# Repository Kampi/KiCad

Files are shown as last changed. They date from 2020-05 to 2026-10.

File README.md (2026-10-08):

# KiCad

## Table of Contents

- [KiCad](#kicad)
  - [Table of Contents](#table-of-contents)
  - [About](#about)
  - [Setup](#setup)
    - [Required Tools](#required-tools)
    - [Setup Instructions](#setup-instructions)
      - [1. Install the Tools](#1-install-the-tools)
      - [2. Clone the Repository](#2-clone-the-repository)
      - [3. Set the KICAD\_LIBRARY Environment Variable](#3-set-the-kicad_library-environment-variable)
      - [4. Authenticate Git and the GitHub CLI](#4-authenticate-git-and-the-github-cli)
      - [5. Configure VS Code and GitHub Copilot](#5-configure-vs-code-and-github-copilot)
    - [Project Initialization Script](#project-initialization-script)
      - [What the Script Does](#what-the-script-does)
      - [Usage](#usage)
      - [Non-Interactive Usage](#non-interactive-usage)
  - [Directories](#directories)
  - [PCB Template Structure](#pcb-template-structure)
    - [Template Naming Convention](#template-naming-convention)
    - [Available Templates](#available-templates)
    - [Template Selection](#template-selection)
    - [Adding Custom Templates](#adding-custom-templates)
  - [CI/CD Pipelines](#cicd-pipelines)
    - [PCB](#pcb)
    - [Changelog Check](#changelog-check)
    - [Documentation](#documentation)
    - [Code Style Check](#code-style-check)
    - [PlatformIO Firmware](#platformio-firmware)
    - [ESP-IDF Component](#esp-idf-component)
    - [Component Release](#component-release)
  - [Release Workflow](#release-workflow)
    - [Version Scheme](#version-scheme)
    - [create-dev-branch Skill](#create-dev-branch-skill)
    - [create-release Skill](#create-release-skill)
      - [Prerequisites](#prerequisites)
      - [Usage of the Skill](#usage-of-the-skill)
      - [What the Skill Does](#what-the-skill-does)
      - [Files Changed by the Skill](#files-changed-by-the-skill)
  - [GitHub Secrets Configuration](#github-secrets-configuration)
  - [GitLab CI/CD Variables](#gitlab-cicd-variables)
  - [How to Obtain API Keys](#how-to-obtain-api-keys)
  - [Resources](#resources)
  - [Maintainer](#maintainer)

## About

My private KiCad repository with symbols, 3D models (most of the models are delivered by the part manufacturer, [GrabCAD](https://grabcad.com/), [3D ContentCentral](https://www.3dcontentcentral.com/Default.aspx) or [SnapEDA](https://www.snapeda.com/)), and footprints for different projects.

Please write an e-mail to [DanielKampert@kampis-elektroecke.de](mailto:DanielKampert@kampis-elektroecke.de) if you have any questions.

## Setup

### Required Tools

| Tool | Version | Needed for |
| ---- | --- | --- |
| [KiCad](https://www.kicad.org/download/) | 10.0 or later | Schematic and PCB design, `kicad-cli` for ERC/DRC. The template files and the PCB pipeline use KiCad 10 |
| [Git](https://git-scm.com/downloads) | Current version | Repository handling, init scripts, releases |
| [Python 3](https://www.python.org/downloads/) | 3.8 or later | JSON processing in `init-project.sh`, file updates in the `create-dev-branch` and `create-release` skills |
| Bash | 4.0 or later | `init-project.sh`, project scripts and the `create-dev-branch` and `create-release` skills (Git Bash or WSL on Windows) |
| PowerShell | 5.1 or later | `init-project.ps1` (Windows only) |
| curl | Current version | License download in `init-project.sh` |
| [GitHub CLI](https://cli.github.com/) (`gh`) | Current version | Pushing with the logged in GitHub user in the `create-dev-branch` and `create-release` skills, watching pipelines and reading releases in the `create-release` skill |
| [Visual Studio Code](https://code.visualstudio.com/) | Current version | Running the `create-dev-branch` and `create-release` skills |
| [GitHub Copilot](https://github.com/features/copilot) | Copilot subscription | Agent mode for the `create-dev-branch` and `create-release` skills |
| [KiBot](https://github.com/INTI-CMNB/KiBot) | Optional | Local output generation with `kibot_launch.sh` (the CI/CD pipeline uses its own container) |

### Setup Instructions

#### 1. Install the Tools

**Linux (Debian/Ubuntu):**

```bash
sudo apt update
sudo apt install git python3 curl
```

Install KiCad from the [KiCad download page](https://www.kicad.org/download/linux/) and the GitHub CLI by following the [official installation instructions](https://github.com/cli/cli/blob/trunk/docs/install_linux.md). The distribution packages of both tools are often outdated.

**Windows (PowerShell):**

```powershell
winget install --id KiCad.KiCad
winget install --id Git.Git
winget install --id Python.Python.3.12
winget install --id GitHub.cli
winget install --id Microsoft.VisualStudioCode
```

Add the `bin` directory of KiCad (e.g. `C:\Program Files\KiCad\10.0\bin`) to the `PATH`, so that `kicad-cli` can be found.

Verify the installation:

```bash
git --version
python3 --version
kicad-cli version
gh --version
```

#### 2. Clone the Repository

The template and the plugins are included as Git submodules, so clone the repository recursively:

```bash
git clone --recurse-submodules https://github.com/Kampi/KiCad
```

For an existing clone, fetch the submodules with `git submodule update --init --recursive`.

#### 3. Set the KICAD_LIBRARY Environment Variable

Create an environment variable with the name `KICAD_LIBRARY` and set it to the location of the repository.

**Linux/macOS:**

```bash
echo 'export KICAD_LIBRARY="$HOME/Projects/KiCad"' >> ~/.bashrc
source ~/.bashrc
```

**Windows (PowerShell):**

```powershell
[Environment]::SetEnvironmentVariable("KICAD_LIBRARY", "C:\KiCad", "User")
```

Restart KiCad and all terminals afterwards.

#### 4. Authenticate Git and the GitHub CLI

```bash
git config --global user.name "John Doe"
git config --global user.email "john.doe@example.com"
gh auth login --hostname github.com --git-protocol https --web
gh auth setup-git
gh auth status
```

`gh auth setup-git` makes Git use the credentials of the active GitHub CLI account, so `git push` and `gh` always use the same account. With several accounts, add them with `gh auth login` and switch with `gh auth switch --user <username>`.

#### 5. Configure VS Code and GitHub Copilot

1. Install the GitHub Copilot extension and sign in with your GitHub account
2. Open the generated project folder (not the `KiCad` repository) in VS Code, so that the skills in `.github/skills/` are found
3. Make sure agent skills are enabled (`chat.useAgentSkills`, enabled by default)
4. **Windows only**: The skill uses Bash commands. Set Git Bash as the terminal profile for agent commands:

   ```json
   "chat.tools.terminal.terminalProfile.windows": {
       "path": "C:\\Program Files\\Git\\bin\\bash.exe"
   }
   ```

### Project Initialization Script

The `Scripts` directory contains initialization scripts for creating new projects from the template:

- `Scripts/init-project.ps1` - Windows PowerShell script
- `Scripts/init-project.sh` - Linux/macOS Bash script

The scripts find the template via the `KICAD_LIBRARY` environment variable or, if it is not set, relative to their own location.

#### Project Types

The scripts ask for the project type and keep only the directories, the firmware profile and the GitHub Actions workflows that belong to it:

| No. | Project type | Hardware | Firmware profile | Result |
| --- | --- | --- | --- | --- |
| 1 | Hardware (default) | Yes | `firmware/blank` | KiCad project with an empty firmware directory |
| 2 | Hardware with PlatformIO firmware | Yes | `firmware/platformio` | KiCad project and a PlatformIO project in `firmware/` |
| 3 | PlatformIO firmware | No | `firmware/platformio` | PlatformIO project in `firmware/` |
| 4 | ESP-IDF component | No | `firmware/esp-idf-component` | Component in the repository root |

- **PlatformIO profile**: ESP32 (`esp32dev`) with the ESP-IDF framework. The platform `espressif32 @ 7.1.3` contains ESP-IDF v6.1. Hardware independent code in `lib/` is tested on the host with the `native` environment
- **ESP-IDF component profile**: Component for ESP-IDF v6.1 or later with `idf_component.yml`, an example project in `examples/basic` and its own `README.md` and `CHANGELOG.md`. The sources are named after the repository (`my-component` becomes `my_component.h`)
- Project types without hardware get no KiCad project, no `hw-*` workflows and no release skills. The GitLab CI pipelines are not adapted to the project type yet
- A component cannot be combined with hardware in one repository, because the component release and the hardware release both use the tag `x.y.z`

#### What the Script Does

1. **Project metadata**: Prompts for project name, board name, designer, email, repository URL, company, main branch, target directory and the [project type](#project-types)
2. **PCB template selection** (project types with hardware): Lists the PCB templates from `Template-Project/hardware/` and applies the selected one
3. **Project structure**: Copies the complete template (hardware, firmware, CAD, 3D print, scripts, GitHub Actions workflows, GitLab CI pipelines and agent skills), removes template artifacts such as backups, `VARIABLES.md` and the Git data of the template, and applies the project type
4. **Renaming**: Renames the `hardware` directory to the lowercase board name and all `Template.*` files to `<BoardName>.*`
5. **Metadata**: Updates the text variables in the `.kicad_pro` file (`PROJECT_NAME`, `BOARD_NAME`, `DESIGNER`, `COMPANY`, release date and revision), the sheet title of the main schematic, `kibot_main.yaml` and the workflow settings
6. **License**: Prompts for an open source license (or no license) and downloads the license text
7. **Placeholders**: Replaces all `${...}` placeholders in every text file of the project, including the GitLab CI pipelines and the agent skills
8. **Documentation**: Creates the AsciiDoc scaffolding in `firmware/docs/` (not for the ESP-IDF component)
9. **Git repository**: Initializes the repository with the main branch, the remote `origin`, the commit message template `.github/.commit-msg-template` and an initial commit, and optionally pushes it

#### Usage

**Windows (PowerShell):**

```powershell
cd C:\path\to\KiCad
.\Scripts\init-project.ps1
```

**Linux/macOS (Bash):**

```bash
cd /path/to/KiCad
./Scripts/init-project.sh
```

The script guides you through an interactive setup. Afterwards the target directory contains a fully configured KiCad project. The Bash script checks whether Python 3 is installed and prints installation instructions if it is missing.

#### Non-Interactive Usage

For automated or scripted usage, you can pipe all inputs to the initialization script using `echo`:

**Windows (PowerShell):**

```powershell
"MyProject`nMyBoard`nJohn Doe`njohn.doe@example.com`nhttps://github.com/user/repo`nMyCompany`nmain`nC:\Projects`n1`n1`n1`nn" | .\Scripts\init-project.ps1
```

**Linux/macOS (Bash):**

```bash
echo -e "MyProject\nMyBoard\nJohn Doe\njohn.doe@example.com\nhttps://github.com/user/repo\nMyCompany\nmain\n/home/$(whoami)/projects\n1\n1\n1\nn" | ./Scripts/init-project.sh
```

**Input Order:**

1. Project name (e.g., "MyProject")
2. KiCad board name (e.g., "MyBoard", or press Enter to use project name)
3. Designer name (e.g., "John Doe")
4. Designer email (e.g., `john.doe@example.com`)
5. GitHub repository URL (e.g., `https://github.com/user/repo`) - username and repository name are extracted automatically
6. Company name (optional, or press Enter to skip)
7. Main branch name (default: "main")
8. Target directory (default: current directory)
9. Project type selection (1-4, default: "1" for hardware, see [Project Types](#project-types))
10. PCB template selection (number, e.g., "1" for first template). Only asked for project types with hardware, leave it out for the types 3 and 4
11. License selection (1-11, e.g., "1" for MIT)
12. Push to GitHub now (y/N, default: no)

**Note:** Empty values (just `\n` or backtick-n in PowerShell) will use the default value for that field.

## Directories

The repository contains the following directories and files:

- `3D`: 3D models in STEP format used by the library
- `Applications`: Additional applications, e.g. the Part-DB integration
- `Design-Blocks`: KiCad design blocks
- `Drawings`: Inventor projects for different 3D models
- `Footprints`: Part footprints
- `GitHub`: Third-party libraries as Git submodules (Espressif KiCad libraries)
- `Layout`: Drawing sheet templates
- `Plugins`: KiCad plugins as Git submodules (KiCad Project Initialization Plugin)
- `Scripts`: Project initialization scripts
- `Symbols`: Part symbols
- `Template-Project`: Project template (Git submodule)
- `KiCad Workflow.md`: Development workflow, version numbering and GitHub workflow
- `AGENTS.md`: Project guidelines for AI coding agents (GitHub Copilot, Claude Code, Codex, Cursor and others). `.github/copilot-instructions.md` and `CLAUDE.md` only point to it. Rules for single areas are in `.github/instructions/`

## PCB Template Structure

The project template supports multiple PCB stackup configurations through template files. Templates must be placed in the `Template-Project/hardware/` directory.

### Template Naming Convention

PCB template files must follow this exact naming pattern:

```sh
Template - <manufacturer>_<thickness>_<layers>-layer.kicad_pcb
```

**Components:**

- `Template - ` - Fixed prefix (required)
- `<manufacturer>` - PCB manufacturer name (e.g., pcbway, jlcpcb, oshpark)
- `<thickness>` - Board thickness with unit (e.g., 1.6mm, 0.8mm, 2.0mm)
- `<layers>` - Number of copper layers (e.g., 2, 4, 6)
- `-layer.kicad_pcb` - Fixed suffix (required)

### Available Templates

- `Template - pcbway_1.6mm_2-layer.kicad_pcb` - PCBWay, 1.6mm thickness, 2 layers
- `Template - pcbway_1.6mm_4-layer.kicad_pcb` - PCBWay, 1.6mm thickness, 4 layers

### Template Selection

During project initialization, the script will:

1. Scan the `Template-Project/hardware/` directory for all template files
2. Parse the manufacturer, thickness, and layer count from each filename
3. Present an interactive menu with available templates
4. Copy the selected template as the base PCB file for the new project and remove the unused templates

### Adding Custom Templates

To add a new PCB template:

1. Create a KiCad PCB file with your desired stackup and design rules
2. Name the file following the convention above
3. Place it in the `Template-Project/hardware/` directory
4. The template will automatically appear in the selection menu

**Template Requirements:**

- Must be a valid `.kicad_pcb` file
- Should include appropriate design rules for the manufacturer
- Should contain stackup configuration matching the specified layer count
- Recommended to include manufacturer-specific constraints (trace width, spacing, etc.)

## CI/CD Pipelines

The project template contains pipelines for GitHub Actions (`Template-Project/.github/workflows/`) and GitLab CI (`Template-Project/.gitlab/ci/`, included by `Template-Project/.gitlab-ci.yml`).

The GitHub Actions workflows are grouped by a prefix in the file name and in the workflow name, so they are listed together in the Actions view. The initialization script removes the workflows that do not belong to the project type.

| Prefix | Workflow name | Area | Runs for |
| --- | --- | ---- | --- |
| `hw-` | `Hardware / ...` | KiCad project | Changes in the hardware directory |
| `fw-` | `Firmware / ...` | Firmware and components | Changes in the firmware sources |
| `docs-` | `Documentation / ...` | Documentation | Changes in `firmware/docs/` |
| `common-` | `Common / ...` | All project types | Every push and pull request |

| Pipeline | GitHub Actions | GitLab CI |
| --- | --- | --- |
| PCB | `hw-pcb.yaml` | `pcb.gitlab-ci.yml` |
| Changelog check | `common-changelog.yaml` | `changelog.gitlab-ci.yml` |
| Documentation | `docs-build.yaml` | `documentation.gitlab-ci.yml` |
| Code style check (AStyle) | `fw-format.yaml` | `astyle.gitlab-ci.yml` |
| Code style check (West) | - | `west-astyle.gitlab-ci.yml` |
| PlatformIO firmware | `fw-platformio.yaml` | - |
| ESP-IDF component | `fw-esp-component.yaml` | - |
| Component release (ESP-IDF) | `fw-esp-component-release.yaml` | `esp-component-release.gitlab-ci.yml` |

### PCB

**Trigger**: Push to `dev` or a development branch `x.y.z_Dev` / `x.y_Dev`, push of a version tag `x.y.z`, or manual start. The GitHub workflow only runs for branch pushes that change the hardware directory or `hw-pcb.yaml`. Tag pushes always start it

A push to `main` or `master` does not start the GitHub workflow. The main branch only receives releases, and a release is built by its tag. The GitLab pipeline still runs for `main` and `master` (except changes to `*.md`)

A branch `x.y_Dev` only triggers the build. Releases always use the three-part [version scheme](#version-scheme) `x.y.z`

Generates the hardware outputs with KiBot in the `kicad10_auto_full` container:

- **Variant-based builds**: Uses the variant from `kibot_variant`. Tag pushes always use `RELEASED`
- **Outputs**: Schematic PDF, Gerbers, drill files, BoM, assembly documents, 3D renders and reports. The outputs are uploaded as workflow artifact (GitLab: job artifact) and not committed. Only the netlist XML is pushed back to the branch, because the next run reads the sheet titles from it
- **ERC/DRC checks**: Only for the `CHECKED` and `RELEASED` variants
- **BoM check**: `scripts/python/check-bom.py` compares the generated BoM (CSV and XLSX) with the schematic. The check fails when a fitted component is missing in the BoM, when the BoM lists a component that is not fitted or excluded from the BoM, or when the CSV and the XLSX BoM differ. A failed check is reported as error, but does not stop the pipeline or the release: GitHub shows an error annotation for the step `Check BoM against schematic`, GitLab marks the job `pcb:check_bom` as failed with a warning. The report lists the components that are not expected in the BoM by reason (DNP, test points, mounting holes, ...) and is shown in the job summary (GitLab: `bom_check.md` in the artifact of `pcb:check_bom`). The result is also stored as Markdown checklist `<board>-bom_check.md` next to the BoM, so it is part of the artifact and the release. The checklist contains the automatic checks and the components for the manual review
- **Cost analysis**: Runs KiCost with the distributor API keys. Missing keys do not fail the pipeline
- **Release** (tag pushes only): Updates `CHANGELOG.md` on the main branch, creates the GitHub/GitLab release with the outputs as ZIP file and publishes the outputs to GitHub/GitLab Pages. GitHub Pages is only updated by releases, so it always shows the state of the latest release

**Variants**:

- `DRAFT`: Schematic only, generates PDF, netlist and BoM (skips ERC/DRC)
- `PRELIMINARY`: Full outputs without ERC/DRC. Set by the `create-dev-branch` skill
- `CHECKED`: Full outputs with ERC/DRC. Set by the `create-release` skill
- `RELEASED`: Full outputs with ERC/DRC, automatically used for version tags

### Changelog Check

**Trigger**: Pull/merge requests targeting `main` or `master`, push to `main`, `master` or `dev`

Validates the changelogs of the project. The GitHub workflow checks `<board>/CHANGELOG.md`, `firmware/CHANGELOG.md` and `CHANGELOG.md` (ESP-IDF component) and skips the files that do not exist. The GitLab pipeline checks `<board>/CHANGELOG.md`:

- The `## [Unreleased]` section must exist
- Entries must be grouped under `**Added:**`, `**Changed:**`, `**Fixed:**` or `**Removed:**`
- Each entry must start with a dash and a space

Example:

```markdown
## [Unreleased]

**Added:**

- New feature description (#12)

**Fixed:**

- Bug fix description (#13)
```

### Documentation

**Trigger**: Push to `main` or `master` and pull/merge requests that change `firmware/docs/**` or the pipeline file, or manual start

- Converts all AsciiDoc files in `firmware/docs/` to HTML and PDF and generates a landing page
- Publishes the result to GitHub/GitLab Pages

### Code Style Check

**Trigger**: Pull/merge requests, push to `main`, `master` or `dev`, or manual start. The GitHub workflow only runs when C/C++ sources, `scripts/` or the workflow file change

- Builds AStyle and runs `scripts/bash/check-format.sh` in dry-run mode. Style violations are reported, files are not changed
- The GitHub workflow checks the directories from `source_dirs` (`firmware`, for the ESP-IDF component `src include examples`). Without arguments the script checks `src` and `include`
- GitLab only: `west-astyle.gitlab-ci.yml` runs `west format --dry-run` for Zephyr/West based firmware (requires a West workspace)

### PlatformIO Firmware

**Trigger**: Pull requests and pushes to `main`, `master`, `dev` or a development branch that change `firmware/` or the workflow file, or manual start

Builds, tests and checks the PlatformIO project in `firmware/` (GitHub Actions only):

- **Build**: Reads the environments from `platformio.ini` and builds every environment except the ones with the `native` platform as a matrix. The firmware images (`*.bin`, `*.elf`) are uploaded as workflow artifact
- **Unit tests**: Runs `pio test -e native` on the host
- **Static analysis**: Runs `pio check` (cppcheck) for every target environment and fails on defects of medium or high severity

The firmware has no release pipeline. A version tag `x.y.z` starts the hardware release only.

### ESP-IDF Component

**Trigger**: Pull requests and pushes to `main`, `master`, `dev` or a development branch (except changes to `*.md`), or manual start

Builds and validates the component in the repository root (GitHub Actions only):

- **Build**: Builds every example in `examples/` in the `espressif/idf` Docker image for each combination of the matrix `idf_version` (default: `v6.1`) and `target` (default: `esp32`). Add versions or targets to the matrix to cover them
- **Validation**: Packs the component with `compote component pack`. This checks `idf_component.yml` without uploading anything

### Component Release

**Trigger**: Push to `main` or `master` (merge of a development branch)

Releases an ESP-IDF component:

- Takes the version from the merge commit (`Merge branch 'x.y.z_Dev'`) or the branch name
- Updates `CHANGELOG.md`, `CMakeLists.txt` and `idf_component.yml`, commits the changes and pushes the tag `x.y.z`
- Creates the GitHub/GitLab release. The GitHub workflow also uploads the component to the ESP Component Registry

## Release Workflow

A hardware release follows the development cycle of the template:

1. Create a development branch `x.y.z_Dev` with the `create-dev-branch` skill. It branches off the main branch, sets the KiBot variant to `PRELIMINARY` and prepares the changelog variables for the release
2. Work on the design and document all changes in the `## [Unreleased]` section of `CHANGELOG.md`
3. Create the release with the `create-release` skill. It merges the development branch into the main branch and pushes the tag `x.y.z`, which triggers the `RELEASED` build and the GitHub release

### Version Scheme

Releases use exactly three numeric parts `x.y.z` (major, minor, patch), e.g. `1.2.0`. A two-part version like `1.2` is not a valid release version, write it as `1.2.0`.

| Item | Format | Example |
| ---- | --- | --- |
| Development branch | `x.y.z_Dev` | `1.2.0_Dev` |
| Release version and tag | `x.y.z`, without prefix or suffix | `1.2.0` |
| Commit of the release preparation | `Prepare Release x.y.z` | `Prepare Release 1.2.0` |
| Changelog variables | `RELEASE_TITLE_x.y.z`, `RELEASE_BODY_x.y.z` | `RELEASE_TITLE_1.2.0` |

The version is defined once by the name of the development branch. The tag, the commit message and the changelog variables are derived from it and are never entered separately.

The `create-dev-branch` skill extends a shorter input to this format (`1.2` becomes `1.2.0`). The `create-release` skill and the tag trigger of the `PCB` pipeline only accept this format. With a branch `1.2_Dev` the skill stops, and a tag `1.2` or `v1.2.0` does not start the release pipeline.

### create-dev-branch Skill

The template contains the agent skill `create-dev-branch` in `Template-Project/.github/skills/create-dev-branch/SKILL.md`. GitHub Copilot finds it there, Claude Code finds it through the pointer in `Template-Project/.claude/skills/create-dev-branch/SKILL.md`. The initialization script copies it into every new project and replaces the placeholders (`${BOARD_NAME}`, `${BOARD_NAME_LOWER}`, `${MASTER_BRANCH}`) with the project values.

The skill prepares a development branch from any state of the main branch, so that only the design work and the changelog entries are missing before the `create-release` skill is started. It requires `git`, `python3`, an authenticated GitHub CLI and a clean working tree. The branch is pushed with the user that is logged in to the GitHub CLI. Start it in the **Agent** mode of the Chat view with `/create-dev-branch`.

1. **Version**: Asks for the version of the next release and extends it to `x.y.z`. Stops if the tag or the branch already exists
2. **Main branch**: Pulls the main branch (`main` or `master`, from `master_branch` in `hw-pcb.yaml`)
3. **Branch**: Creates the development branch `x.y.z_Dev`
4. **Production data**: Removes the production directory (`kibot_output_path` in `hw-pcb.yaml`) with the outputs of the previous release. The netlist XML is kept
5. **Variant**: Sets `kibot_variant` in `.github/workflows/hw-pcb.yaml` to `PRELIMINARY`
6. **Changelog variables**: Adds a free `x.y.z` entry for `RELEASE_TITLE_<version>` and `RELEASE_BODY_<version>` to the KiBot configuration and to the revision history sheet. It uses the unused column (`${RELEASE_TITLE_...}`) following the newest release. If all columns of the table are used, the column of the oldest release is replaced
7. **Commit and push**: Commits `Prepare Development Branch for Release x.y.z` and pushes the branch after a confirmation

The skill is based on the GitHub Actions workflow `hw-pcb.yaml`. It does not change the GitLab CI pipelines.

### create-release Skill

The template contains the agent skill `create-release` in `Template-Project/.github/skills/create-release/SKILL.md`. GitHub Copilot finds it there, Claude Code finds it through the pointer in `Template-Project/.claude/skills/create-release/SKILL.md`. The initialization script copies it into every new project and replaces the placeholders (`${BOARD_NAME}`, `${BOARD_NAME_LOWER}`, `${MASTER_BRANCH}`) with the project values.

The skill is based on the GitHub Actions workflow `hw-pcb.yaml` and the GitHub CLI. It does not support GitLab CI.

#### Prerequisites

- All [required tools](#required-tools) for the skill are installed: `git`, `python3`, `kicad-cli` (KiCad 10 or later) and `gh`
- The GitHub CLI is authenticated with an account that can push to the repository (`gh auth status`). All pushes of the skill are done with this user
- The working tree is clean (`git status --porcelain` is empty)
- The current branch is the development branch `x.y.z_Dev` (three parts, see [Version Scheme](#version-scheme)). The release version is always taken from the branch name
- The `## [Unreleased]` section of `CHANGELOG.md` contains entries
- The tag `x.y.z` does not exist yet
- `kibot_yaml/kibot_pre_set_text_variables.yaml` and the revision history sheet contain a free `x.y.z` entry for the changelog variables, or already the entries for the release version

#### Usage of the Skill

1. Open the project in VS Code and check out the development branch, e.g. `1.2.0_Dev`
2. Open the Chat view and select **Agent** mode
3. Start the skill with the slash command or a prompt:

   ```text
   /create-release
   ```

   ```text
   Create the release for the current development branch.
   ```

4. Confirm the summary (version, development branch, main branch) before the skill pushes anything

The skill stops at the first failing step and reports the error. It never deletes or moves a tag without asking.

#### What the Skill Does

1. **Checks**: Validates the branch name, the project files, the `env` section of `hw-pcb.yaml`, the changelog and the tag
2. **ERC and DRC**: Runs `kicad-cli sch erc` and `kicad-cli pcb drc` (with schematic parity). Errors abort the release, warnings do not
3. **Changelog variables**: Sets the free `x.y.z` entries for `RELEASE_TITLE_<version>` and `RELEASE_BODY_<version>` in the KiBot configuration and in the revision history sheet to the release version
4. **Variant**: Sets `kibot_variant` in `.github/workflows/hw-pcb.yaml` to `CHECKED`
5. **Commit and push**: Commits `Prepare Release x.y.z` and pushes it to the development branch
6. **KiBot pipeline**: Waits for the `Hardware / PCB Data` workflow of the commit with `gh run watch`
7. **Merge**: Pulls the netlist XML generated by the pipeline and merges the development branch into the main branch
8. **Tag**: Creates the tag `x.y.z` and pushes the main branch and the tag atomically
9. **Release pipeline**: Waits for the run of the tag, which builds the release, and reports the URL of the GitHub release. Only this run decides whether the release was successful. The push of the main branch starts no run
10. **Pull**: Pulls the main branch (`main` or `master`, from `master_branch` in `hw-pcb.yaml`) to get the released state with the updated `CHANGELOG.md`

#### Files Changed by the Skill

| File | Change |
| ---- | --- |
| `<board>/kibot_yaml/kibot_pre_set_text_variables.yaml` | Changelog variables of the release version |
| `<board>/Revision History.kicad_sch` | Changelog variables in the revision history table |
| `.github/workflows/hw-pcb.yaml` | `kibot_variant` set to `CHECKED` |

## GitHub Secrets Configuration

Add the secrets in the repository settings under **Settings > Secrets and variables > Actions**.

| Secret Name | Used In | Description | Required |
| --- | --- | --- | --- |
| `MOUSER_KEY` | `hw-pcb.yaml` | Mouser API key for the KiCost price lookup | Optional |
| `DIGIKEY_KEY` | `hw-pcb.yaml` | DigiKey API key for the KiCost price lookup | Optional |
| `TME_KEY` | `hw-pcb.yaml` | TME API key for the KiCost price lookup | Optional |
| `RS_KEY` | `hw-pcb.yaml` | RS API key for the KiCost price lookup | Optional |
| `FARNELL_KEY` | `hw-pcb.yaml` | Farnell API key for the KiCost price lookup | Optional |
| `IDF_COMPONENT_REGISTRY_TOKEN` | `fw-esp-component-release.yaml` | Token for the upload to the ESP Component Registry | Required for ESP-IDF components |

`GITHUB_TOKEN` is provided automatically. The workflows use it to push the netlist and the changelog, to create releases and to deploy GitHub Pages. For the Pages deployment set **Settings > Pages > Source** to **GitHub Actions**.

## GitLab CI/CD Variables

Add the variables in the project settings under **Settings > CI/CD > Variables** and mark them as masked.

| Variable Name | Used In | Description | Required |
| --- | --- | --- | --- |
| `WORKFLOW_PAT` | `pcb.gitlab-ci.yml`, `esp-component-release.gitlab-ci.yml` | Personal access token with the scopes `api` and `write_repository` to push commits and tags and to create releases | Required |
| `MOUSER_KEY` | `pcb.gitlab-ci.yml` | Mouser API key for the KiCost price lookup | Optional |
| `DIGIKEY_KEY` | `pcb.gitlab-ci.yml` | DigiKey API key for the KiCost price lookup | Optional |
| `TME_KEY` | `pcb.gitlab-ci.yml` | TME API key for the KiCost price lookup | Optional |
| `RS_KEY` | `pcb.gitlab-ci.yml` | RS API key for the KiCost price lookup | Optional |
| `FARNELL_KEY` | `pcb.gitlab-ci.yml` | Farnell API key for the KiCost price lookup | Optional |

## How to Obtain API Keys

Only the Mouser API is enabled in `kibot_yaml/kicost_config_local.yaml` of the template. Enable further distributors there before you add their keys.

**Mouser API Key**:

1. Register at [Mouser Electronics](https://www.mouser.com/)
2. Navigate to [API Hub](https://www.mouser.com/api-hub/)
3. Request access to the Search API and copy the key

**DigiKey API Key**:

1. Register at the [DigiKey API Portal](https://developer.digikey.com/)
2. Create an application and copy the client ID and the client secret

**ESP Component Registry Token**:

1. Log in to the [ESP Component Registry](https://components.espressif.com/)
2. Navigate to your profile settings
3. Generate an API token for component uploads

## Resources

- [KiBot Template](https://github.com/nguyen-v/KDT_Hierarchical_KiBot)
- [KiCad Project Template](https://github.com/Kampi/Template-Project)

## Maintainer

- [Daniel Kampert](mailto:DanielKampert@kampis-elektroecke.de)

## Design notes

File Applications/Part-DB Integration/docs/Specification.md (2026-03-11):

# Specification

## Idea

Import a KiCad project release produced by a CI/CD pipeline into a Part-DB server.
The goal is to add new components to the Part-DB database and to represent the PCB
as a hierarchical *Project* inside Part-DB.

## Process

1. Parse the BOM CSV from a given KiCad release directory.
   The release is downloaded by an external CI/CD step; its local path is specified
   in `settings.json` or via the `--release-dir` CLI argument.
2. For each BOM entry that carries a manufacturer part number (MPN):
   - Query Part-DB for an existing part with that exact MPN.
   - If found → record the IRI and continue.
   - If not found → create the part (name = MPN, description, KiCad footprint,
     manufacturer, category derived from the designator prefix) and record the
     new IRI.
3. Create or find a **top-level project** in Part-DB.
   The name is derived from the release directory name by stripping the
   all-uppercase release qualifier and title-casing the remainder
   (e.g. `mainboard-RELEASED` → `Mainboard`).
   A custom name can be provided via `settings.json → project_name` or `--project-name`.
4. Create a **sub-project** (child of the top-level project) whose name equals
   the release directory basename (e.g. `mainboard-RELEASED`).
   The script exits with an error if the sub-project already exists, preventing
   duplicate BOM entries on repeated CI/CD runs.
5. Link every BOM component to the sub-project BOM, including quantity and
   designator references.
6. Upload relevant release documents as attachments to the sub-project
   (schematics PDF/SVG, interactive BOM, DRC/ERC reports, 3D STEP model).

## BOM File Format

Location inside a release: `<release_dir>/Manufacturing/Assembly/*-bom.csv`

CSV columns (the header row uses these exact names):

| Column | Description |
|---|---|
| `Row` | Sequential row number |
| `Quantity Per PCB`| Number of identical components per board |
| `References` | Space-separated list of designators (e.g. `C1 C2`) |
| `Value` | Component value or part value string |
| `Datasheet` | URL to the datasheet (often Mouser-hosted) |
| `Footprint` | KiCad footprint reference |
| `Description` | Human-readable component description |
| `manf` | Manufacturer name |
| `manf#` | Manufacturer part number (MPN) — primary key |

## Designator-Prefix to Category Mapping

The category is derived from the alphabetic prefix of the first designator
in the *References* column.  The mapping can be extended in `settings.json`.

| Prefix | Category |
|---|---|
| `BT` | Batteries |
| `C` | Capacitors |
| `D` | Diodes |
| `F` | Fuses |
| `IC` | Integrated Circuits |
| `J` | Connectors |
| `K` | Relays |
| `L` | Inductors |
| `LED`  | LEDs |
| `M` | Modules |
| `P` | Connectors |
| `Q` | Transistors |
| `R` | Resistors |
| `SW` | Switches |
| `TH` | Sensors |
| `U` | Integrated Circuits |
| `X` | Connectors |
| `Y` | Crystals & Oscillators |

Unknown prefixes fall back to `default_category` (default: `"Miscellaneous"`).

ICs that require finer sub-classification (voltage regulators, LED drivers, …)
can be separated in a later step by editing the parts inside Part-DB, or the
`category_map` override in `settings.json` can map specific prefixes to custom
categories before the first import.

## Part-DB API

The application communicates with the Part-DB REST API (API Platform / JSON-LD).

Base URL: configured in `settings.json → api_url`
Authentication: `Authorization: Bearer <api_key>` header.

Endpoints used:

| Method | Endpoint | Purpose |
|---|---|---|
| GET | `/categories` | List categories (for lookup/create) |
| POST | `/categories` | Create a new category |
| GET | `/manufacturers` | List manufacturers |
| POST | `/manufacturers` | Create a new manufacturer |
| GET | `/footprints` | List footprints |
| POST | `/footprints` | Create a new footprint |
| GET | `/parts?filter[manufacturerProductNumber]=…` | Search part by MPN |
| POST | `/parts` | Create a new part |
| GET | `/projects` | List projects |
| POST | `/projects` | Create a project (top-level or sub) |
| POST | `/project_bom_entries` | Add a BOM line item to a project |
| GET | `/attachment_types` | List attachment types |
| POST | `/attachment_types` | Create an attachment type |
| POST | `/attachments` | Upload a file attachment (multipart/form-data) |

## File Structure

```sh
app/
├── app.py              Main CLI entry point
├── partdb_client.py    Part-DB REST API client
└── bom_parser.py       KiCad BOM CSV parser
settings.json.template  Settings file template
requirements.txt        Python dependency list
LICENSE                 GNU General Public License v3
.github/
└── copilot-instructions.md  Coding standards for GitHub Copilot
```

## Settings File (`settings.json`)

| Key | Required | Description |
|---|---|---|
| `api_url` | yes | Part-DB API base URL |
| `api_key` | yes | Part-DB bearer token — **never commit to VCS** |
| `release_dir` | no | Default release directory path |
| `project_name` | no | Override the auto-derived top-level project name |
| `default_category`| no | Fallback category for unknown prefixes (default: `Miscellaneous`) |
| `category_map` | no | Override/extend the default designator-prefix mapping |

## CLI Reference

```sh
python app/app.py [OPTIONS]

Options:
  -s, --settings FILE       Settings JSON file (default: settings.json)
  -r, --release-dir DIR     KiCad release directory (overrides settings)
  -n, --project-name NAME   Top-level project name (overrides auto-detection)
      --skip-attachments    Do not upload release documents as attachments
      --dry-run             Simulate all steps, no writes to Part-DB
  -v, --verbose             Debug-level logging
```

## CI/CD Integration

The application can be included in a CI/CD workflow as a Git submodule or by
installing it from the repository.  A minimal GitHub Actions step:

```yaml
- name: Import release to Part-DB
  run: |
    pip install -r requirements.txt
    python app/app.py \
      --release-dir "${{ env.RELEASE_DIR }}" \
      --settings ci/settings.json
```

The `settings.json` used in CI should provide the API key via a repository
secret (never hardcode it).

## Rules for the Project

- Python 3.8+ command-line application
- `settings.json` for runtime configuration (API key, paths, category overrides)
- GPLv3 license; file header: `Daniel Kampert <DanielKampert@kampis-elektroecke>`
- `requirements.txt` for pip-installable dependencies
- Application entry point: `app/app.py`
- Coding standards defined in `.github/copilot-instructions.md`

## Open Items

- Supplier article numbers (e.g. Mouser order codes) are not present in the
  KiCad BOM CSV.  Adding them would require a separate lookup step via a
  distributor API (Mouser, Digikey, …) and is not yet implemented.

## Resources

- Part-DB API: https://inventory.kampert.synology.me/api

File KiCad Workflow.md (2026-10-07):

# KiCad Workflow

## Table of Contents

- [KiCad Workflow](#kicad-workflow)
  - [Table of Contents](#table-of-contents)
  - [Related files](#related-files)
    - [Project template](#project-template)
    - [Commit message template](#commit-message-template)
  - [Create a new project](#create-a-new-project)
  - [Version Numbering](#version-numbering)
    - [Major](#major)
    - [Minor](#minor)
    - [Fix](#fix)
  - [GitHub workflow](#github-workflow)
    - [Milestones](#milestones)
    - [Issue tracker](#issue-tracker)
    - [Types](#types)
      - [Added](#added)
      - [Removed](#removed)
      - [Changed](#changed)
  - [Working with the Issue Tracker](#working-with-the-issue-tracker)
    - [Branch Workflow](#branch-workflow)
    - [Initialization of the development branch](#initialization-of-the-development-branch)
  - [Publishing a new Release](#publishing-a-new-release)
  - [Maintainer](#maintainer)

## Related files

### Project template

You can find a ready-to-use project template inthe  `Template-Project` directory of the [KiCad library](https://github.com/Kampi/KiCad) project.

### Commit message template

The commit message for a feature or bug fix must look like this (you can use `git commit -s` to add the `Signed-off-by` text):

```txt
<Type>: Issue #<Number>

(If needed) Description of changes

Closes ...

Signed-off-by: Your name <Your Email>
```

You can find a commit message template in the `github` directory of the project. Open a git shell in the project directory and use the command

```sh
git config commit.template .github/.commit-msg-template
```

to change the template locally for the project. If no template is available, feel free to create one yourself.

## Create a new project

1. Copy the template project (`__Project__`) and rename it
2. Rename the KiCad files in `hardware` according to your project
3. Open `.github/workflows/hw-pcb.yaml`

    - Replace the variables in the `env` section according to your project

4. (Optional): If you want to use a logo, replace and rename `dummy_logo.png` in `Logos` with your logo. Then change the logo path in `hardware/README.md` and `hardware/kibot_yaml/kibot_main.yaml`
5. Open `hardware/kibot_yaml/kibot_main.yaml` to replace the following text variables:

| Variable | Description |
|:----|:-----|
| PROJECT_NAME | The name of the KiCad project |
| BOARD_NAME | The name of the project |
| COMPANY | Your company name |
| DESIGNER | The name of the board designer |
| LOGO | The path to your logo (if needed) |
| GIT_URL | The URL to the Git repository |

## Version Numbering

Format: `Major.Minor.Fix`

### Major

Increment when the hardware architecture or overall project structure changes significantly.

### Minor

Increment when new features or major improvements are introduced.

### Fix

Increment for minor bug fixes, layout corrections, or documentation updates.

## GitHub workflow

### Milestones

A **milestone** is created for every release and is used to group related features and bug fixes.
The naming convention is:

```txt
<Project> Version <Major> Release <Minor> (Fix <Fix>)
```

Example:

```txt
Watch-DK Version 1 Release 2
````

A new development branch named `<Major>.<Minor>.<Fix>_Dev` is created from the main branch for this milestone.
When this branch is initialized:

- The KiBot workflow state in the CI/CD configuration is set to `PRELIMINARY`.

The initial commit message must be:

```txt
Prepare Development Branch for Release <Major>.<Minor>.<Fix>
```

> **NOTE**
> You can use the `create-dev-branch` skill of the project to run these steps automatically.

### Issue tracker

The **issue tracker** is used to manage all bugs, features, and tasks.
Each issue must:

Be assigned to a specific milestone.

Have the correct type and labels.

### Types

#### Added

#### Removed

#### Changed

General to-dos such as documentation improvements, refactoring, or cleanup tasks.

## Working with the Issue Tracker

All features and bug fixes are developed in the development branch of their assigned milestone.
Each commit affecting the PCB project must also include an entry in the [Unreleased] section of the `CHANGELOG.md` file:

```txt
- <Short description> (#<Issue number>)
```

Entries should be placed under the correct category:

- `Fix`
- `Added`
- `Removed`
- `Changed`

### Branch Workflow

You can either:

- Fork the development branch, commit your changes there, and open a PR, or
- Create a feature branch from the development branch, make your changes, and open a PR from that branch.

The KiBot workflow state may be set to `DRAFT` or `PRELIMINARY` as needed, but **must not** be set to `CHECKED`.

### Initialization of the development branch

A development branch is created from the `main` branch. The first commit should always reset the workflow state to `DRAFT` or `PRELIMINARY`. The first commit message is always

```sh
Initialize development branch for version ...
```

## Publishing a new Release

A new release is pushed to `main` by using a Pull Request. The request can be created as a draft either when a new development branch is created or later, when all the work is done. The title of the Pull Request should always be `Release <Major>.<Minor>.<Fix>`.

To prepare a new release:

1. Create a commit in the development branch with the header:

```sh
Release <Major>.<Minor>.<Fix>
```

2. Update all release-specific data:

- Set the release title and body in the schematic’s **Revision History** page:
- Change RELEASE_TITLE_... → RELEASE_TITLE_<Major>.<Minor>.<Fix>
- Update the changelog variables in kibot_pre_set_text_variables.yaml.

3. Fix all **ERC** and **DRC** errors.
4. Set the KiBot workflow to `CHECKED`.
5. Push all changes to the feature branch.
6. Merge the feature branch into the main branch.
7. Create and push a new Git tag for the version:

```sh
git pull <Upstream> <Main>
git tag <Major.Minor.Fix>
git push <Upstream> <Major.Minor.Fix>
```

## Maintainer

- [Daniel Kampert](mailto:DanielKampert@kampis-elektroecke.de)

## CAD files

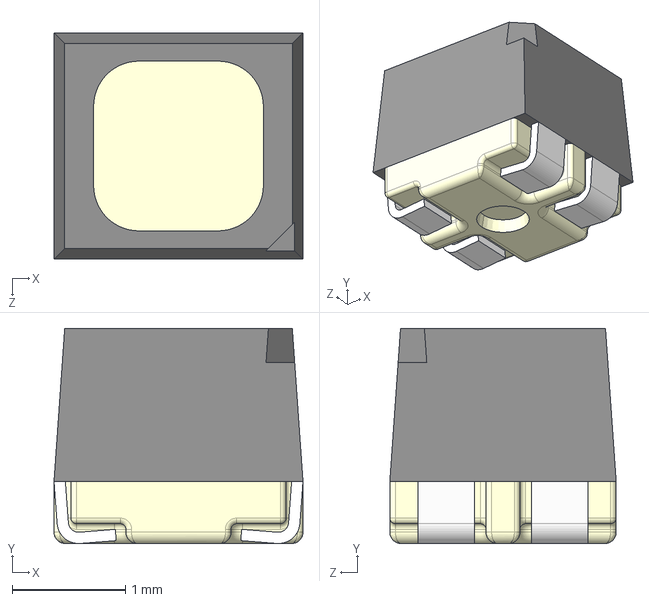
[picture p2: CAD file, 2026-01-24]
3D/Broadcom/ASMB-KTF0-0A306.stp
2.20 x 1.90 x 2.00 mm

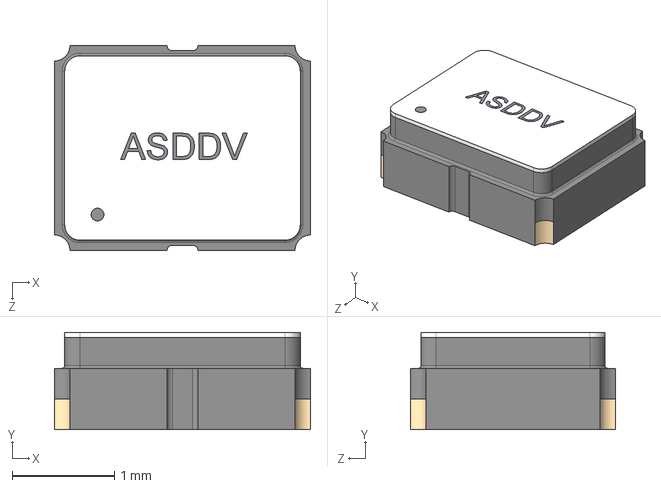
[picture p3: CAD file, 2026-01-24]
3D/Abracon/ASDDV.stp
2.50 x 0.951 x 2.00 mm

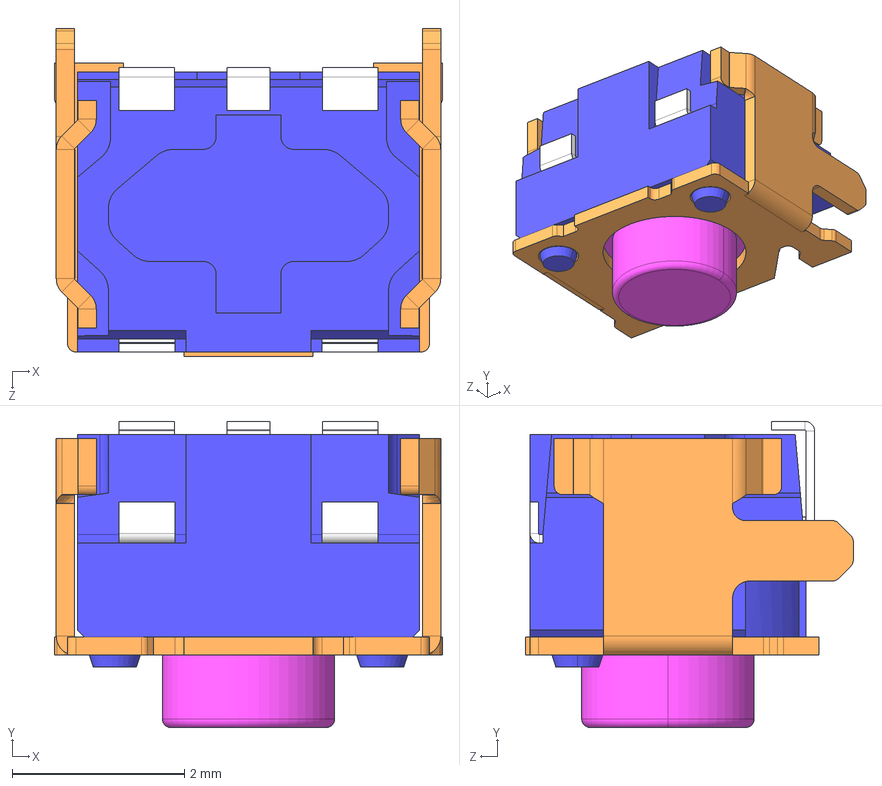
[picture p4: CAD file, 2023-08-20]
3D/Alps Alpine/SKRTLA.stp
4.50 x 3.55 x 3.80 mm

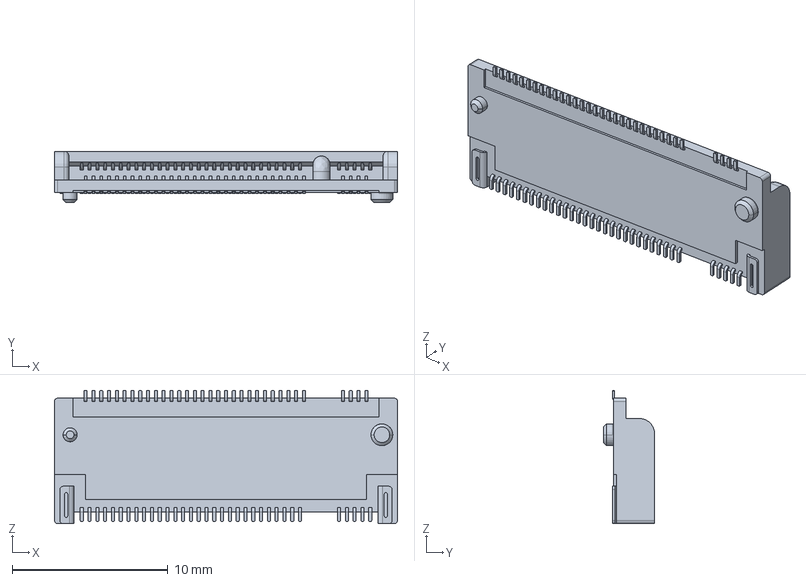
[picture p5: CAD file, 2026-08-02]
3D/Amphenol/MDT275M03001.stp
22.0 x 3.30 x 8.55 mm

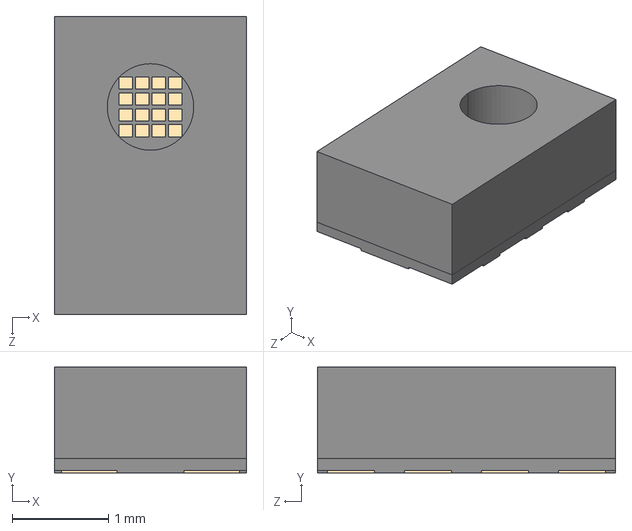
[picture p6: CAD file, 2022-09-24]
3D/ams/AS7341.stp
2.00 x 1.10 x 3.10 mm

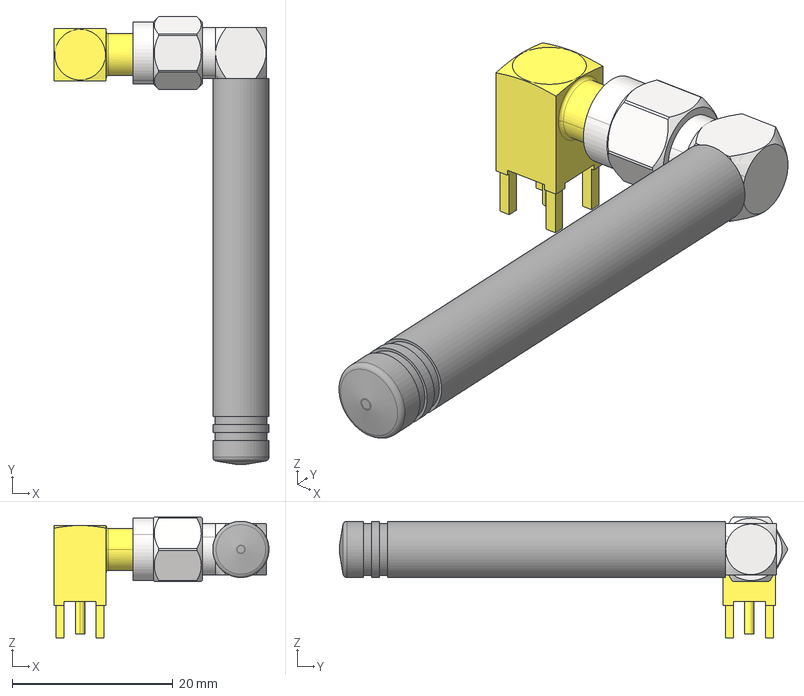
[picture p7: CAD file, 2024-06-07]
3D/Antenna/GSM_ANTENNA_45mm_90deg_RIGHT.stp
26.8 x 55.7 x 15.0 mm
RP-SMA FEMALE TO 90DEG MALE

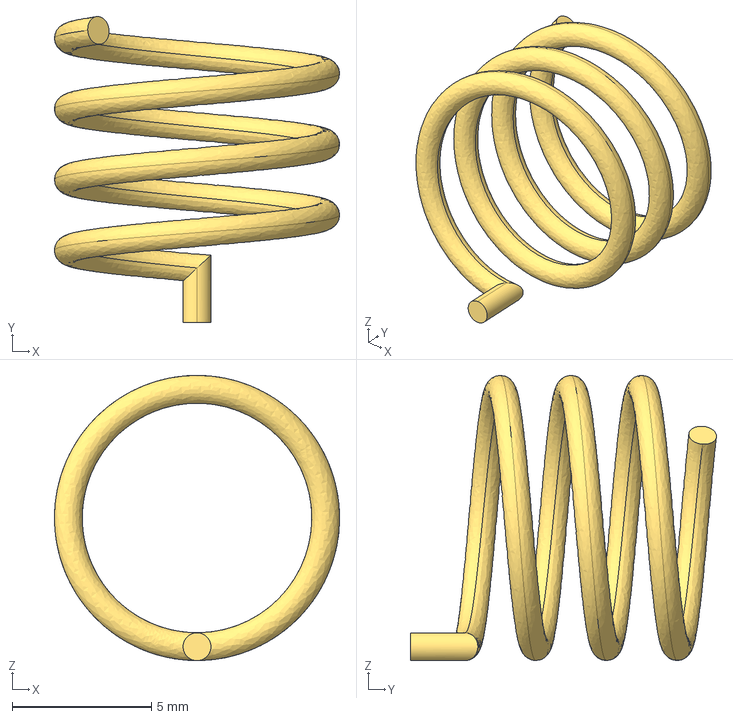
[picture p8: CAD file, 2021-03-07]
3D/Antenna/LoRa/HelixAntenna.stp
10.2 x 11.0 x 10.2 mm

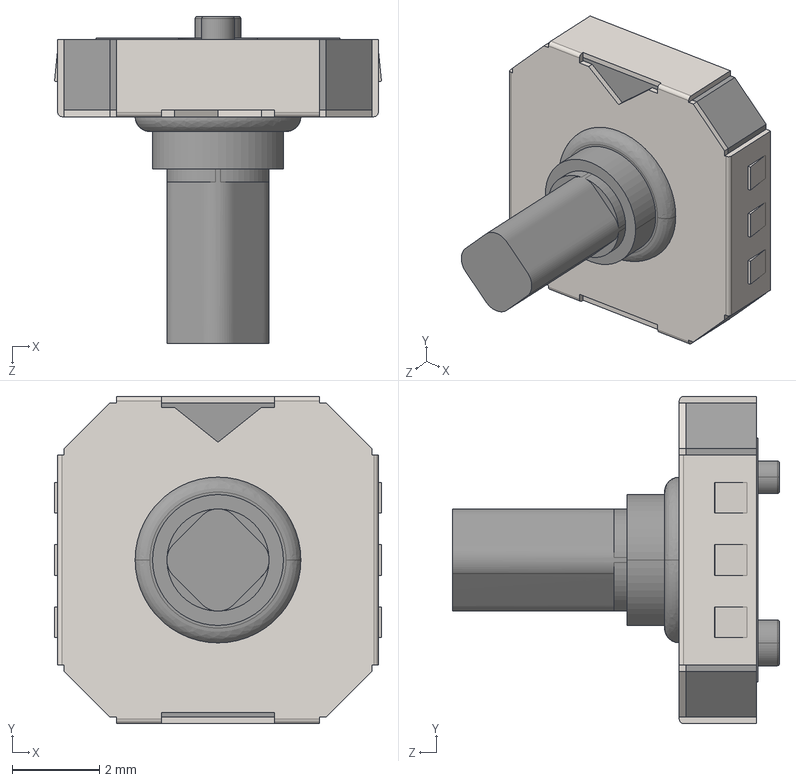
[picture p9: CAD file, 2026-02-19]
3D/Apem/MU-BUE70R.stp
7.50 x 7.50 x 7.50 mm

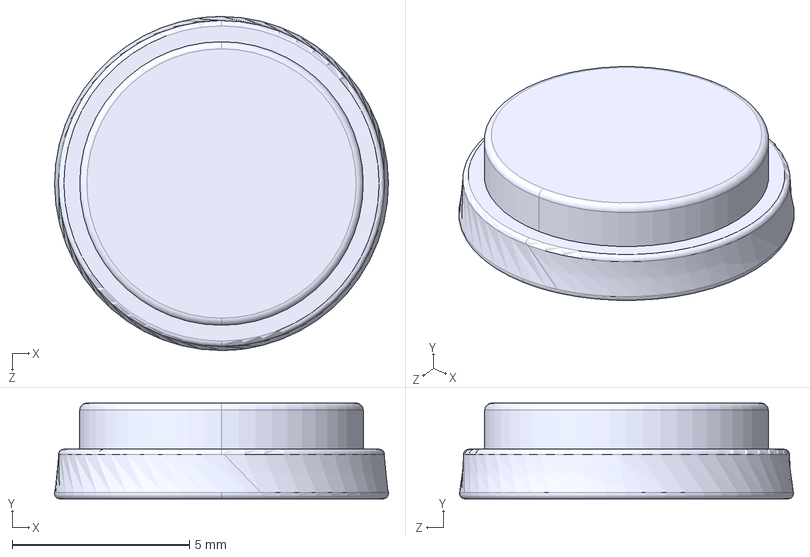
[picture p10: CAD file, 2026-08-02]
3D/Battery/CR927.stp
9.42 x 2.70 x 9.42 mm

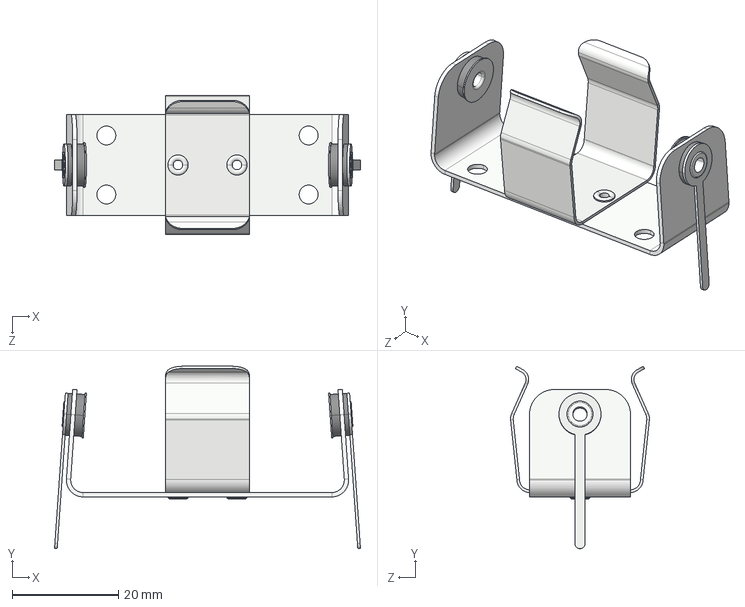
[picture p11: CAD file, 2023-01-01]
3D/Batteryholder/Keystone/2224.stp
57.6 x 34.4 x 26.2 mm

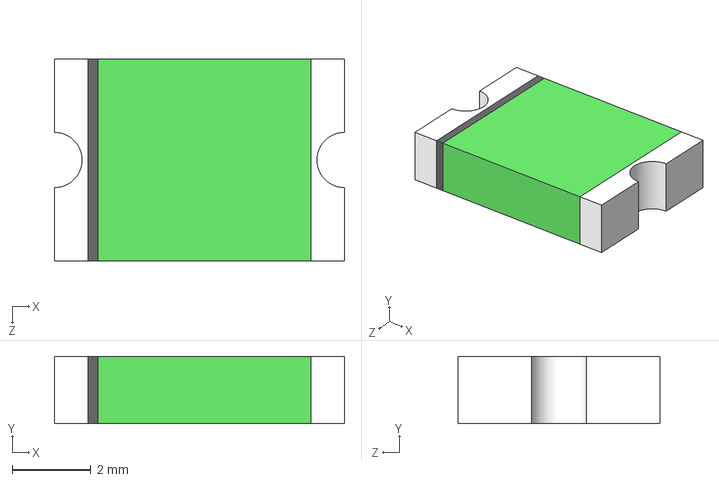
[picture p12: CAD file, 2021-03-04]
3D/BelFuse/0ZCF0075AF2C.stp
7.36 x 1.70 x 5.12 mm

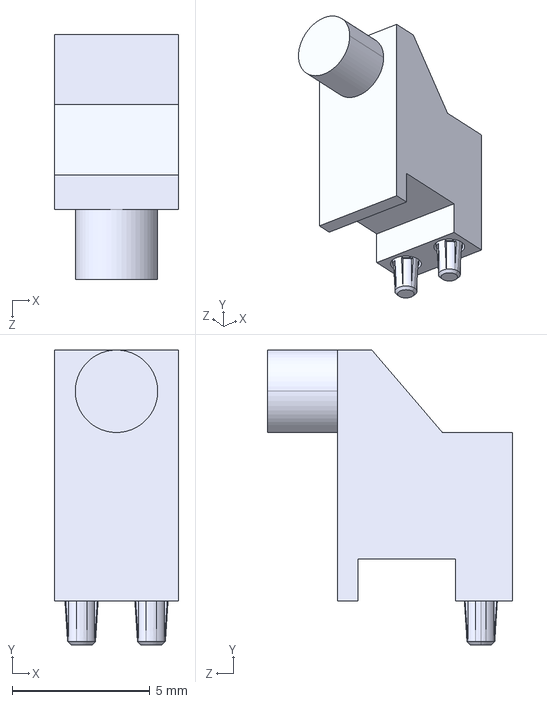
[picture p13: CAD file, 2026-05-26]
3D/Bivar/SLP3-300-100-F.stp
4.52 x 10.7 x 8.89 mm

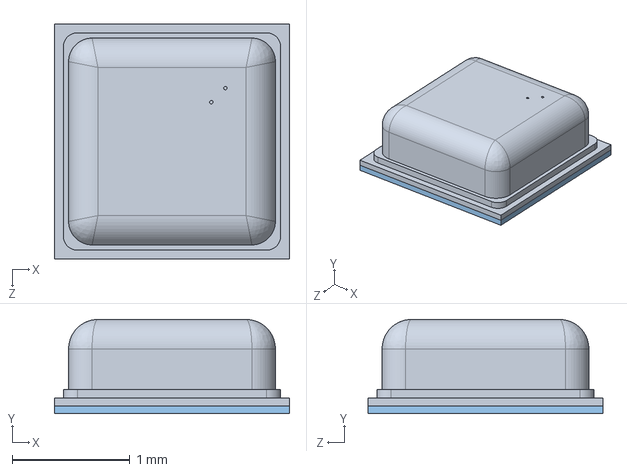
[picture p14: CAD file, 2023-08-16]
3D/Bosch/BMP581.stp
2.00 x 0.801 x 2.00 mm

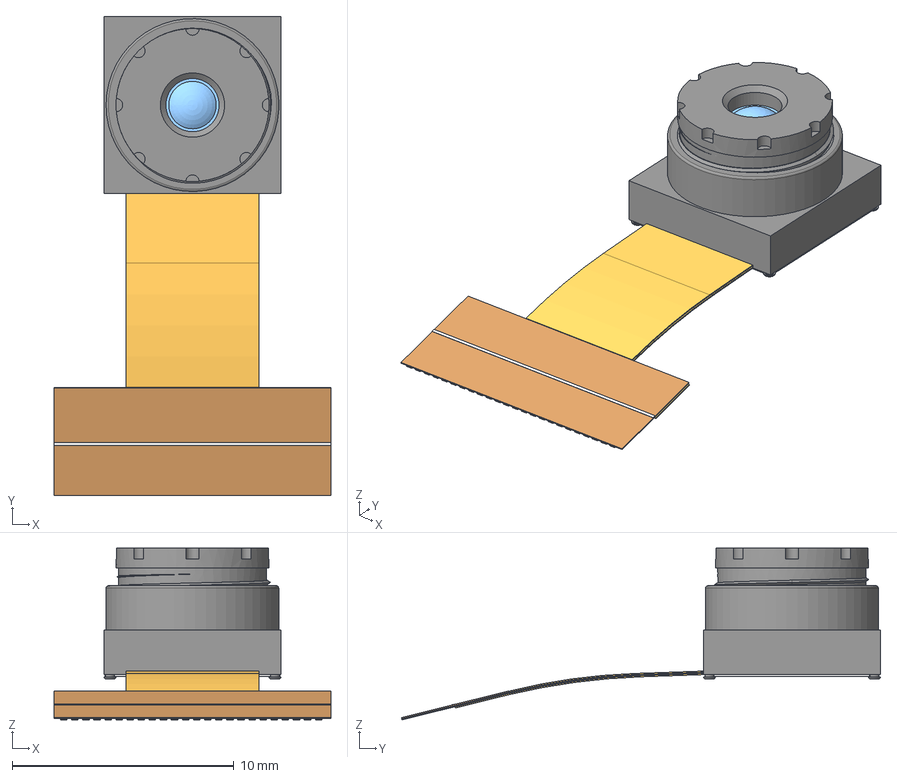
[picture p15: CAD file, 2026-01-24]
3D/Camera/OV2640.step
12.5 x 21.6 x 7.76 mm
Lense
plate
tail006
plate006
conn043
film003
silk004

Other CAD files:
3D/Coilcraft/XFL4020.stp
3D/Connector_254/Pin Header 1x13 TH Pitch 2.54mm.stp
3D/Connector_254/preci-dip/8fm-38-0006-02-146.stp
3D/Connector_Audio/QingPu/PJ398SM_S_pin_centered.stp
3D/Abracon/ABS07.stp
3D/Abracon/ATXAIG-H13_ABR.stp
3D/Amphenol/10133475-10001LF.stp
3D/Amphenol/101P014FB110.stp
3D/Amphenol/101R014FB110.stp
3D/Amphenol/20021121-00012XXLF.stp
3D/Amphenol/20021321-00012XXLF.stp
3D/Amphenol/77317-412-12LFc.stp
3D/Amphenol/901-144.stp
3D/Amphenol/A-1JB.stp
3D/Amphenol/F32Q-1A7H1-11022.stp
3D/Amphenol/F32Q-1A7H1-11024.stp
3D/Amphenol/F32R-14.stp
3D/Amphenol/F32R-24.stp
3D/Amphenol/F32R-6.stp
3D/Amphenol/MDT320B03001.stp
3D/Amphenol/MDT420A01001.stp
3D/Amphenol/MDT420B03001.stp
3D/Amphenol/MDT420M03001.stp
3D/Amphenol/SFV24R-3STBE1HLF.stp
3D/Amphenol/U77A1118200T.stp
3D/Analog Devices/LT3652EMSE#PBF.stp
3D/Analog Devices/MAX17048G+T10.stp
3D/Analog Devices/MAX30101.stp
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

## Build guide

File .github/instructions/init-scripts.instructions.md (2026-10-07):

---
description: "Use when editing the project init scripts init-project.sh or init-project.ps1: prompts, input order, placeholders, template copy, license, Git initialization."
applyTo: "Scripts/**"
---
# Init Scripts

- Implement every change in `init-project.sh` and `init-project.ps1` with the same behavior and the same step numbers
- Port every change to `Plugins/KiCad-Project-Initialization-Plugin/kicad_project_init.py` (prompts become dialog fields). The plugin must create the same files as the scripts, except the Git repository. Compare the results with `diff -r` for every project type
- Bash: snake_case functions, quoted variables, `[[ ]]`, `print_color` for output, Python 3 for JSON
- PowerShell: approved verb-noun functions, typed parameter blocks, native cmdlets, `Write-ColorOutput` for output
- Check that a file exists before changing it. Exit with 1 on errors
- Keep the scripts idempotent

## Global Variables and Placeholders

Global variables pass the project data to the template. Never reuse their names for local variables, use lowercase names such as `local_project_name`.

The scripts replace these `${NAME}` placeholders in every text file of the new project:

| Placeholder | Value |
| --- | ----- |
| `PROJECT_NAME` | Project name (input) |
| `BOARD_NAME` | Board name (input, default: project name) |
| `BOARD_NAME_LOWER` | Lowercase board name, also the name of the hardware directory |
| `PROJECT_NAME_ANCHOR`, `BOARD_NAME_ANCHOR` | Markdown anchors of the project and board name |
| `DESIGNER`, `EMAIL` | Designer name and email (input) |
| `COMPANY` | Company name (optional input) |
| `GIT_URL`, `GIT_USER`, `GIT_REPO` | Repository URL (input), user and repository extracted from it |
| `GIT_REPO_LOWER`, `GIT_REPO_UPPER` | Repository name as C identifier in lowercase and uppercase, `-` becomes `_` (ESP-IDF component) |
| `MASTER_BRANCH` | Main branch (input, default: `main`) |
| `REVISION` | Initial version `1.0.0` |
| `RELEASE_DATE`, `RELEASE_DATE_NUM` | Current date as `dd-MMM-yyyy` and `yyyy-MM-dd` |
| `LICENSE_BADGE`, `LICENSE_LINK` | License badge and link (project README only) |

Further global variables: `PROJECT_TYPE`, `PROJECT_TYPE_NAME`, `HAS_HARDWARE`, `FIRMWARE_PROFILE`, `TARGET_DIR`, `TEMPLATE_PATH`, `KICAD_LIBRARY`, `PROJECT_PATH`, `CURRENT_DATE`, `CURRENT_YEAR`, `LICENSE_NAME`, `LICENSE_KEY`, `LICENSE_SELECTION`, `PCB_FILENAME`, `PCB_MANUFACTURER`, `PCB_THICKNESS`, `PCB_LAYERS`.

Don't use the placeholder names in template files for anything else, e.g. KiCad text variables, because the scripts would replace them.

A new project metadata field needs: the prompt in both scripts, the placeholder replacement, and where needed the `text_variables` of the `.kicad_pro`, the `definitions` of `kibot_main.yaml` and the title block of the `.kicad_sch`.

## Input Order

1. Project name
2. KiCad board name (default: project name)
3. Designer name
4. Designer email
5. GitHub repository URL
6. Company name (optional)
7. Main branch name (default: `main`)
8. Target directory (default: current directory)
9. Project type selection (1-4, default: 1)
10. PCB template selection (number, project types with hardware only)
11. License selection (1-11)
12. Push to GitHub now (y/N)

When adding, removing or reordering a prompt, update this list, the header comments of both scripts and the "Non-Interactive Usage" section of [README.md](../../README.md) (both example commands and the input order). Empty input uses the default value.

## Project Types

| No. | Project type | `HAS_HARDWARE` | `FIRMWARE_PROFILE` |
| --- | --- | --- | --- |
| 1 | Hardware | true | `blank` |
| 2 | Hardware with PlatformIO firmware | true | `platformio` |
| 3 | PlatformIO firmware | false | `platformio` |
| 4 | ESP-IDF component | false | `esp-idf-component` |

- The firmware profiles are the directories in `Template-Project/firmware/`. `apply_project_type` / `Set-ProjectType` moves the selected profile to `firmware/` (ESP-IDF component: to the repository root), removes the other profiles and removes the workflows, directories and skills of the other project types
- All steps that change the KiCad project run only with `HAS_HARDWARE`
- A new firmware profile needs: the directory in `Template-Project/firmware/`, the menu entry and the mapping in both scripts, its `fw-` workflows and the documentation in [README.md](../../README.md) (Project Types, CI/CD Pipelines)

## Testing

Run both scripts interactively and non-interactively with empty optional fields, special characters in names, `main` and `master` as main branch, every PCB template and every project type.

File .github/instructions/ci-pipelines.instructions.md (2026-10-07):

---
description: "Use when editing CI/CD pipelines of the project template: GitHub Actions workflows, GitLab CI pipelines, KiBot PCB pipeline, secrets and CI/CD variables."
applyTo: "Template-Project/.github/workflows/**, Template-Project/.gitlab/**, Template-Project/.gitlab-ci.yml"
---
# CI/CD Pipelines

Every pipeline exists for GitHub Actions and GitLab CI. Change both files together:

| Pipeline | GitHub Actions | GitLab CI |
| --- | --- | --- |
| PCB (KiBot) | `hw-pcb.yaml` | `pcb.gitlab-ci.yml` |
| Changelog check | `common-changelog.yaml` | `changelog.gitlab-ci.yml` |
| Documentation | `docs-build.yaml` | `documentation.gitlab-ci.yml` |
| Code style check (AStyle) | `fw-format.yaml` | `astyle.gitlab-ci.yml` |
| Code style check (West) | - | `west-astyle.gitlab-ci.yml` |
| PlatformIO firmware | `fw-platformio.yaml` | - |
| ESP-IDF component | `fw-esp-component.yaml` | - |
| Component release (ESP-IDF) | `fw-esp-component-release.yaml` | `esp-component-release.gitlab-ci.yml` |

- Add new GitLab pipelines to the `include:` list of `Template-Project/.gitlab-ci.yml`
- File names: lowercase with hyphens, `.yaml` for GitHub Actions, `.gitlab-ci.yml` for GitLab CI
- GitHub Actions workflows are grouped by area: file prefix `hw-`, `fw-`, `docs-` or `common-` and the matching workflow name `Hardware / ...`, `Firmware / ...`, `Documentation / ...` or `Common / ...`
- The init scripts select the workflows by these names: `hw-*.yaml` is removed without hardware, `fw-platformio.yaml` and `fw-esp-component*.yaml` without the matching firmware profile, `docs-*.yaml` for the ESP-IDF component. Update `Set-ProjectType` / `apply_project_type` when adding or renaming a workflow
- Restrict `hw-` and `fw-` workflows with `paths` filters to their area. Path filters are not evaluated for tag pushes
- `hw-pcb.yaml` is not triggered by the main branch. A release is built by its tag, and GitHub Pages is only deployed by tag runs, so it always shows the latest release. Don't add `main` / `master` to its branch triggers
- `fw-platformio.yaml` and `fw-esp-component.yaml` have no GitLab CI pipeline yet
- Every file starts with the header comment block (Trigger, Function, Variables, Secrets). Keep it up to date
- Configuration at workflow level: GitHub `env:` in lowercase (`kibot_input_dir`), GitLab `variables:` in uppercase (`KIBOT_INPUT_DIR`). Values set by the init scripts are `${UPPERCASE}` placeholders
- A value used in several pipelines (e.g. the main branch) must be changed in all GitHub and GitLab files
- KiBot jobs use the image `ghcr.io/inti-cmnb/kicad10_auto_full:latest`
- The `create-release` skill uses the file name `hw-pcb.yaml` and its `env` keys `kibot_input_dir`, `kicad_board`, `master_branch` and `kibot_variant`. Update the skill when renaming them
- Document new pipelines, secrets and variables in [README.md](../../README.md) (CI/CD Pipelines, GitHub Secrets Configuration, GitLab CI/CD Variables)

## Platform Differences

| Concept | GitHub Actions | GitLab CI |
| --- | --- | --- |
| Tag push | `github.ref_type == 'tag'` | `CI_COMMIT_TAG` |
| Branch name | `github.ref_name` | `CI_COMMIT_BRANCH` |
| Repository URL | `github.server_url` + `github.repository` | `CI_PROJECT_URL` |
| Token for pushes and releases | `GITHUB_TOKEN` | `WORKFLOW_PAT` (CI/CD variable) |
| Secrets | Repository secrets | Masked CI/CD variables |
| Artifacts | `actions/upload-artifact` | `artifacts:` |
| Pages | `actions/deploy-pages` | `pages` job with `public/` |

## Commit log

2019-10-16 Rename directories, add footprints and 3D models
    [T73XF-VISHAY.stp, T73XH-VISHAY.stp, T73XW-VISHAY.stp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]
2019-10-16 Change library path and environment variable
    [694106301002 (rev1).stp]
2019-10-17 Add some parts
    [c-5749231-1-o-3d.stp]
2019-10-17 Add 3D models
    [Potentiometer Blue.stp, Trimmer_Piher_PT-15.step]
2019-10-18 Add 3D models, add potentiometer footprint for bourns potentiometer
    [3386-B.stp, 3386-T.stp, 3386P001XXX-EY5.stp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]
2019-10-18 Add manufacturing template
    [Template.xlsx]
2019-10-18 Add JST connector
    [B02B-PASK-1.stp, BM02B-PASS-TF.stp]
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2019-11-11 Add EG1271 switch
    [EG1271.stp]
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2020-01-17 Add different 3D part models
    [B02B-PASK.stp, B04B-PASK-1.stp, B06B-PASK-1.stp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]
2020-01-24 Add 3D model for Panasonic switches
    [ESE24MH1.stp]
2020-03-03 Add digilent I2S2 PMOD 3D model
    [PmodI2S2.stp]
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2020-05-07 Add PMOD OLED and JST B2B-PH-SM4-TB step model
    [B2B-PH-SM4-TB.stp, PmodOLED.stp]
2020-05-08 Change pin type for the 'LiPo+' pin of the Particle Argon, add JST 3D models
    [S4B-PH-SM4-TB.stp]
2020-05-11 Add more 3D models
    [DSG (S-PWSON-N8).stp, PmodI2S2.stp, PmodOLED.stp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]
2020-05-12 Update footprints and 3D
    [B02B-PASK-1.stp, B02B-PASK.stp, B06B-PASK-1.stp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]
2020-05-18 Update footprints, BOM scripts and project template
    [Template.xlsx]
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2020-05-27 Fix footprint for BH1726
2020-05-29 Modify Template, add Phoenix contact footprints and 3D models, fix wrong Epson oscillator footprint
    [PhoenixContact_MPT_0,5_4-4-2,54.stp, PhoenixContact_MSTBA_2,5_18-G-5,08_1x18_P5.08mm_Horizontal.stp, Template.xlsx]
2020-05-31 Add VEML6070
    [VEML6070.stp]
2020-06-03 Add parts
    [1042.0001.ipt, 1042.ipt, 1042.stp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]
2020-06-09 Add footprints, update BOM template
    [77317-412-06LFc.stp, Template.xlsx]
2020-06-10 Update library
    [18650.stp, Template.xlsx]
2020-06-19 Update library!
    [ATE1D-2M3-10-Z.stp]
2020-07-15 Fix wrong footprints for TE connectors
2020-07-30 Update 3D models and footprints
    [59006986_DIBLZ-AK-30x5-IM3-10.stp, NRS5030.stp, WUERTH 40023 6 cheese head screw ISO 14580 3x6 Blank.stp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]
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2020-08-25 Fix some footprint errors
2020-09-04 Fix missing solder mask for Kingbright SC56 footprint
2020-09-07 Add IR receiver footprint
    [TSOP283.stp]
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2020-09-10 Add Abracon crystals
    [ABS07L.stp]
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2020-09-23 Add step models for Omron relays
    [G5Q_1A.step]
2020-09-28 Add more battery holder
    [206.stp, 208.stp, 2997.stp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]
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2020-09-30 Update 3D models
    [7447706221.stp, QFN20 5x5.stp, QFN20-4x4.stp]
2020-10-09 Add step models from Harwin
    [M52-040023W0545.stp, M52-5100545.stp]
2020-12-02 Add 3D model for USB connector
    [632712000011.stp]
2021-02-05 Misc: - Add more 3D models
    [101P014FB110.stp, 101R014FB110.stp, 2337019-1.stp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]
2021-03-04 - Add more 3D models - Add different symbols and footprints
    [0ZCF0075AF2C.stp, 1042.stp, 1048.stp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]
2021-03-07 - Add more 3D models - Add Kicad template project - Add more libraries and symbols
    [1042.stp, 1043.stp, 1048.stp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]
2021-05-16 Add more footprints
    [2-1734592-4.stp, LQH3NPN2R2MJRL.stp, PTV09A-2x15f-xxxx.stp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]
2021-09-12 - Add more symbols and 3D models
    [B7B-PH-K-S.stp, ESP8266-ESP07.stp, SOT363.stp]
2021-11-06 Add more libraries
    [B3B-PH-K-S.stp, B4B-PH-K-S.stp, B5B-PH-K-S.stp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]
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2022-07-31 - Add footprints and 3D models from Espressif
    [1571300-2.stp, QLS6B-FKW-CNSNSF043.stp, WSON-10-Therm.stp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]
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2023-08-22 Update template project to KiCad 7
    [__Project__.kicad_pcb, __Project__.kicad_sch, __Project__.sch]
2023-08-31 Add new footprints, change project template structure
    [SHF-105-01-L-D-SM-TR.stp, __Project__.xlsx]
2023-09-16 - Add MLPF-WB55-01E3 - Add STM32WB15CCU - Add BSH205G2AR - Add PMV50XNEAR
    [MLPF-WB55-01E3_STM.stp]
2023-09-16 Add library for NDK crystals
    [NX2016SA_NDK.stp, XTAL_NX2012SA_NDK.stp]
2023-09-17 - Add cap sense footprint for moisture sensor - Add modified 2.4 GHz antennas from the KiCad library. Fix issue 2520 (missing net ties)
2023-09-19 - Add Molex connector - Fix wrong pathes for 3D models
    [781710002.stp, VFQFN68-8x8mm_STM.stp]
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2023-10-31 - Add 3D models for Tag Connect cables - Fix wrong pin configuration for STM32 GND pins - Add NTS0104GU12 - Add VEML7700 - Add VEML6035 - Add TS3USB221A - Add pole indication for RD90_LZH0230529-004_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
2023-11-05 - Replace the ":KICAD_LIBRARY:" variable format with "${KICAD_LIBRARY}" for the footprints to make them work with KiBot - Add KiBot template - Fix missing variables in footprint pathes
2023-11-05 fixup! - Replace the ":KICAD_LIBRARY:" variable format with "${KICAD_LIBRARY}" for the footprints to make them work with KiBot - Add KiBot template - Fix missing variables in footprint pathes
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2023-11-07 - Fix wrong 3D model pathes in Broadcom and Cree footprint library
2023-11-07 - Add different symbols from EAGLE export
    [SO8N.stp, TSSOP8.stp, UFDFPN5.stp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]
2023-11-29 - Add Knowles SPH0645IM4G - Fix undefined pins in nPM1300 symbol
    [SPH0645lM4H.stp]
2023-12-06 Add CUI Devices library
    [CMT-322-65-SMT-TR.stp]
2023-12-27 - Add RV-3028-C7 from Micro Crystal - Update README - Add position markers for footprints - Add Diodes Incorporated library - Add Infineon library - Add symbols for ROHM
    [RV-3028-C7.stp, WSON-8-8x6.stp]
2023-12-28 Fix wrong path for 3D model in CMT-322-65-SMT-TR footprint
2024-01-12 - Fix empty footprint in Alps Alpine symbol - Add ST ESDALC6V1P5 - Fix missing mask layer in E-Switch library - Fix wrong courtyard in RAK3172 symbol - Fix empty ZIP files in KiBot template - Fix mis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
    [FTSH-105-01-F-DV-K-P-TR.stp]
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2024-02-06 - Fix double pin in SPH0645LM4H-B symbol - Add 3D model for SPH0645LM4H-B footprint
    [SPK0641HT4H.stp]
2024-02-06 Add QFN 3D model
    [QFN-32-1EP_5x5mm_P0.5mm_EP3.6x3.6mm.step]
2024-06-07 - Add MAXM8616 - Add MAX32664 - Add FH19C-8S-0.5SH(10) - Add 101R014FB110 and 101P014FB110 - Add more 3D models - Fix wrong pin number for ADC1 and ADC2 pin in RAK3172 symbol - Add CR2032 - Add KiBot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
    [1004627.stp, 2005280070.stp, 5047542520.stp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]
2024-09-03 - Add LM66200 - Add SOT-883 package - Add PMZ550UNEYL
    [BH-18650-PC.stp, SOT-5X3-8.stp, SOT-883.stp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]
2024-09-20 Add Traco power symbol
    [G6QE.stp, RAC10E-SK_277.stp, __Project__.xlsx]
2024-09-21 Add Phoenix Contact connectors, sync design of footprints
    [490107670612.stp, MC-1-5-2-G-3-81.stp, MSTBA-2-5-2-G-5-08-LR.stp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]
2026-01-24 - Update project template - More Footprints - CI/CD improvements and fixes
    [10133475-10001LF.stp, 1054500101.stp, 1734839-6.stp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]
2026-02-05 Add new SD card holder
    [MSD-4-A.stp]
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2026-04-15 Revise issue types in KiCad Workflow documentation
    Updated issue types in the KiCad Workflow documentation to reflect new categories: Added, Removed, and Changed.
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2026-04-24 Update footprint and template projects
    [LFCSP-10.stp, M-FLAT-2.stp, TPS2121RUXT.stp]
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2026-05-07 Update footprints and template project
    [ST1S14PHR_3V3_3A.kicad_sch]
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2026-06-01 Rework Phoenix footprints, add Molex footprints
    [MSTB-2-5-2-GF-5-08.stp, MSTBA-2-5-2-G.stp, MSTBA-2-5-HC-2-G-5-08.stp]
2026-06-03 Add 3D models from Toradex
    [Verdin Industrial Heatsink Type 1 V1.0B.stp, Verdin Industrial Heatsink Type 1 V1.1A.stp]
2026-06-03 Fix wrong name for the KiCad project
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2026-06-08 Update template project to the latest version, add more footprints
    [1367073-1.stp, U77A1118200T.stp]
2026-06-22 Add IMST wmBus modules
    [RU104_C100(-L_1v3_ufl).stp, RU109_C100(-HP_UFL_1v0) (1).stp, RU109_C100(-HP_UFL_1v0) 1.stp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]
2026-06-30 Fix wrong Mean Well footprint
2026-07-01 Fix wrong Keystone footprint
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2026-07-28 Fix wrong pin definitions
2026-07-30 Fix some footprints
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2026-08-25 Add 3D models, update footprints
    [MB1404-H563ZI-C01.stp, RAC05-K.step, X2QFN-8.stp]
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
